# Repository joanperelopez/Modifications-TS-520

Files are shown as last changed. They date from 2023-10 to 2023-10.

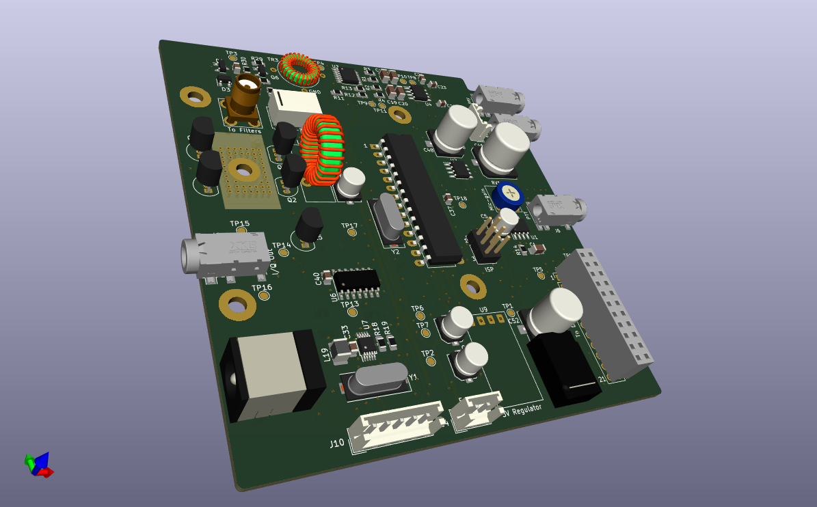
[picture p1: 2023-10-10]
KICAD/mod_TS520/mod_TS520.png

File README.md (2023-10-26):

# Modifications-TS-520

I Started reparing and adjusting my Kenwood transceiver TS-520, but I saw some articles about how to create a device to read the frequency of operation. I decide to include it. I continued including new features as: s-meter, band indicator, spectrum frequency, mode of operation and some others indicators.
As appeared in the picture I use two microcontrollers: one for display and interface, and the second one for the FHT.

This device is inspired in the work of Stephen Leander KV6O, but I changed everything.

On the final PCBs you can see that there are terminals coded from JP1 to JP8. Once the PCB components are assembled, these terminals must be shorted each two with a drop of solder. The grounds of the different circuits are isolated from each other and are only connected to the general ground at these points (star ground).
The VCCs are configured in the same way.

You can use all the documentation that appears in the repository as long as it is not used for commercial purposes.

WhatsApp Image 2023-10-10 at 12 25 15-3

The experiments for the design of the electronic circuits and the microcontroller began with a breadboard and the RF circuits mounted directly on a copper plate.

Top_Assbly

This is the final appearance of the circuit in the TOP side.

Bottom_Assbly

This is the final appearance of the circuit in the BOTTOM side.

The way to calculate the frequency at which the TS-520 emits and receives is a mathematical operation between three different frequencies: CAR which is the frequency of the beat oscillator. VFO which, as its name indicates, is the variable frequency oscillator signal and HET which is a fixed signal from a quartz oscillator and which is different in each band.
Each of these frequencies are amplified and applied to an ATmega328P that makes the readings, the mathematical operations and finally displays the frequency on a graphic screen. 

The band is automatically displayed using the HET information.

The operating mode (USB, LSB and CW) is identified by the frequency of the CAR input and is displayed on the corresponding indicator.

The information from the red LEDs that the TS-520 has is input into the ATmega328P and shown on the display.

The AGC (Automatic Gain Control) signal is conditioned and input into the ATmega328P to display the signal intensity (s-meter).

The RF signal before the SSB and CW filters enters a RF receiver of 3,395MHz that incorporates a Tayloe detector. Once detected, the baseband signal in I/Q format enters the second ATmega328P where it is processed and the FHT is done. This frequency information is transmitted to the first ATmega328P that will display it on the screen. The FHT is like FFT but it uses only the real part, so the CPU load and the complexity is the half.
It is not possible to do the entire process on a single ATmega328P since the FHT consumes almost all the processor resources.

Captura de Pantalla 2023-10-26 a las 16 57 25
PBC layout

Captura de Pantalla 2023-10-26 a las 16 58 39

PCB layout

Schematic

Two shields are provided for the RF sections of the receiver. These should be fitted only after both sections are tested and working correctly.
Connectors J7 and J12 are used to program ATmega328P microcontrollers.
Connectors J5 and J6 connect to the IL9341 2.4" display.

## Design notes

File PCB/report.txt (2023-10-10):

Trazado a '/Users/perelopezveraguas/Documents/Proyectos de RADIOFRECUENCIA/MODIFICACIONES TS-520 /PCB/GERBER/mod_TS520-F_Cu.gbr'.
Trazado a '/Users/perelopezveraguas/Documents/Proyectos de RADIOFRECUENCIA/MODIFICACIONES TS-520 /PCB/GERBER/mod_TS520-B_Cu.gbr'.
Trazado a '/Users/perelopezveraguas/Documents/Proyectos de RADIOFRECUENCIA/MODIFICACIONES TS-520 /PCB/GERBER/mod_TS520-F_Silkscreen.gbr'.
Trazado a '/Users/perelopezveraguas/Documents/Proyectos de RADIOFRECUENCIA/MODIFICACIONES TS-520 /PCB/GERBER/mod_TS520-B_Silkscreen.gbr'.
Trazado a '/Users/perelopezveraguas/Documents/Proyectos de RADIOFRECUENCIA/MODIFICACIONES TS-520 /PCB/GERBER/mod_TS520-F_Mask.gbr'.
Trazado a '/Users/perelopezveraguas/Documents/Proyectos de RADIOFRECUENCIA/MODIFICACIONES TS-520 /PCB/GERBER/mod_TS520-B_Mask.gbr'.
Trazado a '/Users/perelopezveraguas/Documents/Proyectos de RADIOFRECUENCIA/MODIFICACIONES TS-520 /PCB/GERBER/mod_TS520-Edge_Cuts.gbr'.
Archivo de trabajo Gerber '/Users/perelopezveraguas/Documents/Proyectos de RADIOFRECUENCIA/MODIFICACIONES TS-520 /PCB/GERBER/mod_TS520-job.gbrjob' creado.
Info: Listo.

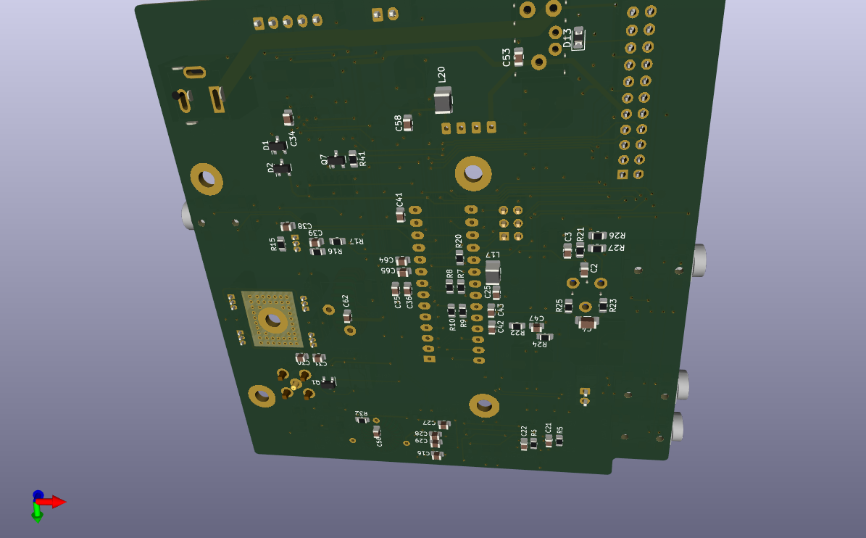
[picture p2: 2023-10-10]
KICAD/mod_TS520/SDR_1.2_Base2.png

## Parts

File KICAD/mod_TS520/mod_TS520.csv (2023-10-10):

Source: | /Users/perelopezveraguas/Documents/KICAD/SDR_1.2/SDR_1.2_Base/SDR_1.2_Base.kicad_sch
Date: | martes, 28 de junio de 2022, 18:18:33
Tool: | Eeschema (6.0.6-0)
Generator: | /Applications/KiCad/KiCad.app/Contents/SharedSupport/plugins/bom_csv_grouped_by_value.py
Component Count: | 147
Individual Components:
Item | Qty | Reference(s) | Value | LibPart | Footprint | Datasheet | Datasheet
 |  | C1 | 1uF | Device:C_Polarized | Capacitor_SMD:C_1206_3216Metric_Pad1.33x1.80mm_HandSolder | ~ | ~
 |  | C2 | 100n | Device:C | Capacitor_SMD:C_0805_2012Metric | ~ | ~
 |  | C3 | 22p | Device:C | Capacitor_SMD:C_0805_2012Metric | ~ | ~
 |  | C4 | 1uF | Device:C_Polarized | Capacitor_SMD:C_1206_3216Metric_Pad1.33x1.80mm_HandSolder | ~ | ~
 |  | C5 | 10uF | Device:C_Polarized | Capacitor_SMD:C_Elec_5x5.4 | ~ | ~
 |  | C6 | 10n | Device:C | Capacitor_SMD:C_0805_2012Metric | ~ | ~
 |  | C16 | 1n | Device:C | Capacitor_SMD:C_0805_2012Metric | ~ | ~
 |  | C17 | .47u | Device:C | Capacitor_SMD:C_1206_3216Metric | ~ | ~
 |  | C18 | .47u | Device:C | Capacitor_SMD:C_1206_3216Metric | ~ | ~
 |  | C19 | .47u | Device:C | Capacitor_SMD:C_1206_3216Metric | ~ | ~
 |  | C20 | .47u | Device:C | Capacitor_SMD:C_1206_3216Metric | ~ | ~
 |  | C21 | 1nF | Device:C | Capacitor_SMD:C_0805_2012Metric | ~ | ~
 |  | C22 | 1nF | Device:C | Capacitor_SMD:C_0805_2012Metric | ~ | ~
 |  | C23 | 100n | Device:C | Capacitor_SMD:C_0805_2012Metric | ~ | ~
 |  | C24 | 100n | Device:C | Capacitor_SMD:C_0805_2012Metric | ~ | ~
 |  | C25 | 100n | Device:C | Capacitor_SMD:C_0805_2012Metric | ~ | ~
 |  | C26 | 100n | Device:C | Capacitor_SMD:C_0805_2012Metric | ~ | ~
 |  | C27 | 100n | Device:C | Capacitor_SMD:C_0805_2012Metric | ~ | ~
 |  | C28 | 10n | Device:C | Capacitor_SMD:C_0805_2012Metric | ~ | ~
 |  | C29 | 100n | Device:C | Capacitor_SMD:C_0805_2012Metric | ~ | ~
 |  | C30 | 100n | Device:C | Capacitor_SMD:C_0805_2012Metric | ~ | ~
 |  | C31 | 33p | Device:C | Capacitor_SMD:C_0805_2012Metric | ~ | ~
 |  | C33 | 100n | Device:C | Capacitor_SMD:C_0805_2012Metric | ~ | ~
 |  | C34 | 1n | Device:C | Capacitor_SMD:C_0805_2012Metric | ~ | ~
 |  | C35 | 100n | Device:C | Capacitor_SMD:C_0805_2012Metric | ~ | ~
 |  | C36 | 10n | Device:C | Capacitor_SMD:C_0805_2012Metric | ~ | ~
 |  | C37 | 100n | Device:C | Capacitor_SMD:C_0805_2012Metric | ~ | ~
 |  | C38 | 10n | Device:C | Capacitor_SMD:C_0805_2012Metric | ~ | ~
 |  | C39 | 10n | Device:C | Capacitor_SMD:C_0805_2012Metric | ~ | ~
 |  | C40 | 100n | Device:C | Capacitor_SMD:C_0805_2012Metric | ~ | ~
 |  | C41 | 10n | Device:C | Capacitor_SMD:C_0805_2012Metric | ~ | ~
 |  | C42 | 100n | Device:C | Capacitor_SMD:C_0805_2012Metric | ~ | ~
 |  | C43 | 10n | Device:C | Capacitor_SMD:C_0805_2012Metric | ~ | ~
 |  | C46 | 250uF | Device:C_Polarized | Capacitor_SMD:C_Elec_10x10.2 | ~ | ~
 |  | C47 | 47n | Device:C | Capacitor_SMD:C_0805_2012Metric | ~ | ~
 |  | C48 | 100uF | Device:C_Polarized | Capacitor_SMD:C_Elec_8x10.2 | ~ | ~
 |  | C52 | 100uF | Device:C_Polarized | Capacitor_SMD:C_Elec_8x10.2 | ~ | ~
 |  | C53 | 100n | Device:C | Capacitor_SMD:C_0805_2012Metric | ~ | ~
 |  | C54 | 100n | Device:C | Capacitor_SMD:C_0805_2012Metric | ~ | ~
 |  | C55 | 100n | Device:C | Capacitor_SMD:C_0805_2012Metric | ~ | ~
 |  | C56 | 100n | Device:C | Capacitor_SMD:C_0805_2012Metric | ~ | ~
 |  | C58 | 100n | Device:C | Capacitor_SMD:C_0805_2012Metric | ~ | ~
 |  | C59 | 10uF | Device:C_Polarized | Capacitor_SMD:C_Elec_5x5.4 | ~ | ~
 |  | C61 | 10uF | Device:C_Polarized | Capacitor_SMD:C_Elec_5x5.4 | ~ | ~
 |  | C62 | 100n | Device:C | Capacitor_SMD:C_0805_2012Metric | ~ | ~
 |  | C63 | 10uF | Device:C_Polarized | Capacitor_SMD:C_Elec_5x5.4 | ~ | ~
 |  | C64 | 12p | Device:C | Capacitor_SMD:C_0805_2012Metric | ~ | ~
 |  | C65 | 12p | Device:C | Capacitor_SMD:C_0805_2012Metric | ~ | ~
 |  | D1 | BAV70 | Diode:BAV70 | Package_TO_SOT_SMD:SOT-23 | https://assets.nexperia.com/documents/data-sheet/BAV70_SER.pdf | https://assets.nexperia.com/documents/data-sheet/BAV70_SER.pdf
 |  | D2 | BAV70 | Diode:BAV70 | Package_TO_SOT_SMD:SOT-23 | https://assets.nexperia.com/documents/data-sheet/BAV70_SER.pdf | https://assets.nexperia.com/documents/data-sheet/BAV70_SER.pdf
 |  | D3 | BAV70 | Diode:BAV70 | Package_TO_SOT_SMD:SOT-23 | https://assets.nexperia.com/documents/data-sheet/BAV70_SER.pdf | https://assets.nexperia.com/documents/data-sheet/BAV70_SER.pdf
 |  | D4 | BAV70 | Diode:BAV70 | Package_TO_SOT_SMD:SOT-23 | https://assets.nexperia.com/documents/data-sheet/BAV70_SER.pdf | https://assets.nexperia.com/documents/data-sheet/BAV70_SER.pdf
 |  | D13 | 20V | Device:D_Zener | Diode_SMD:D_0805_2012Metric_Pad1.15x1.40mm_HandSolder | ~ | ~
 |  | H1 | MountingHole_Pad | Mechanical:MountingHole_Pad | MountingHole:MountingHole_3.2mm_M3_Pad_TopBottom | ~ | ~
 |  | H9 | MountingHole_Pad | Mechanical:MountingHole_Pad | MountingHole:MountingHole_3.2mm_M3_Pad_TopBottom | ~ | ~
 |  | H10 | MountingHole_Pad | Mechanical:MountingHole_Pad | MountingHole:MountingHole_3.2mm_M3_Pad_TopBottom | ~ | ~
 |  | H11 | MountingHole_Pad | Mechanical:MountingHole_Pad | MountingHole:MountingHole_3.2mm_M3_Pad_TopBottom | ~ | ~
 |  | H12 | MountingHole_Pad | Mechanical:MountingHole_Pad | MountingHole:MountingHole_3.2mm_M3_Pad_TopBottom | ~ | ~
 |  | J1 | AudioJack3_PERE | Connector:AudioJack3_PERE | PERE:Jack_3.5mm_PJ311_Horizontal | ~ | ~
 |  | J3 | RF IN/OUT | Connector:Conn_Coaxial | PERE:SMA_Amphenol_901-144_Vertical | ~ | ~
 |  | J4 | AudioJack3_PERE | Connector:AudioJack3_PERE | PERE:Jack_3.5mm_PJ311_Horizontal | ~ | ~
 |  | J5 | AudioJack3_PERE | Connector:AudioJack3_PERE | PERE:Jack_3.5mm_PJ311_Horizontal | ~ | ~
 |  | J6 | AudioJack3_PERE | Connector:AudioJack3_PERE | PERE:Jack_3.5mm_PJ311_Horizontal | ~ | ~
 |  | J7 | ISP | Connector_Generic:Conn_02x03_Counter_Clockwise | PERE:PinHeader_2x03_P2.54mm_Vertical | ~ | ~
 |  | J8 | Barrel_Jack_Switch_Pin3Ring | Connector:Barrel_Jack_Switch_Pin3Ring | PERE:BarrelJack_GCT_DCJ200-10-A_Horizontal | ~ | ~
 |  | J10 | Conn_01x05 | Connector_Generic:Conn_01x05 | Connector_JST:JST_EH_B5B-EH-A_1x05_P2.50mm_Vertical | ~ | ~
 |  | J12 | Conn_02x11_Odd_Even | Connector_Generic:Conn_02x11_Odd_Even | PERE:PinHeader_2x11_P2.54mm_Vertical | ~ | ~
 |  | J14 | Conn_01x02 | Connector_Generic:Conn_01x02 | Connector_JST:JST_EH_B2B-EH-A_1x02_P2.50mm_Vertical | ~ | ~
 |  | J18 | Conn_01x02 | Connector_Generic:Conn_01x02 | Connector_JST:JST_EH_B2B-EH-A_1x02_P2.50mm_Vertical | ~ | ~
 |  | K11 | G6K-2 | Relay:G6K-2 | Relay_SMD:Relay_DPDT_Omron_G6K-2F-Y | http://omronfs.omron.com/en_US/ecb/products/pdf/en-g6k.pdf | http://omronfs.omron.com/en_US/ecb/products/pdf/en-g6k.pdf
 |  | K12 | Tyco | Relay:G6E | PERE:Relay_Single-PERE | https://www.omron.com/ecb/products/pdf/en-g6e.pdf | https://www.omron.com/ecb/products/pdf/en-g6e.pdf
 |  | L16 | 1u | SDR_1-rescue:L_Core_Iron-Device | PERE:Coil_toroid_T50_Vertical
 |  | L17 | 10uH | Device:L_Ferrite | Inductor_SMD:L_1210_3225Metric_Pad1.42x2.65mm_HandSolder | ~ | ~
 |  | L19 | 10uH | Device:L_Ferrite | Inductor_SMD:L_1210_3225Metric_Pad1.42x2.65mm_HandSolder | ~ | ~
 |  | L20 | 10uH | Device:L_Ferrite | Inductor_SMD:L_1210_3225Metric_Pad1.42x2.65mm_HandSolder | ~ | ~
 |  | Q1 | DTC114E | Transistor_BJT:DTC114E | Package_TO_SOT_SMD:SOT-23
 |  | Q2 | BS170 | Transistor_FET:BS170 | Package_TO_SOT_THT:TO-92_Inline | https://www.onsemi.com/pub/Collateral/BS170-D.PDF | https://www.onsemi.com/pub/Collateral/BS170-D.PDF
 |  | Q3 | BS170 | Transistor_FET:BS170 | Package_TO_SOT_THT:TO-92_Inline | https://www.onsemi.com/pub/Collateral/BS170-D.PDF | https://www.onsemi.com/pub/Collateral/BS170-D.PDF
 |  | Q4 | BS170 | Transistor_FET:BS170 | Package_TO_SOT_THT:TO-92_Inline | https://www.onsemi.com/pub/Collateral/BS170-D.PDF | https://www.onsemi.com/pub/Collateral/BS170-D.PDF
 |  | Q5 | BS170 | Transistor_FET:BS170 | Package_TO_SOT_THT:TO-92_Inline | https://www.onsemi.com/pub/Collateral/BS170-D.PDF | https://www.onsemi.com/pub/Collateral/BS170-D.PDF
 |  | Q6 | BFR92A SOT23 | Device:Q_NPN_EBC | Package_TO_SOT_SMD:SOT-23 | ~ | ~
 |  | Q7 | DTC114E | Transistor_BJT:DTC114E | Package_TO_SOT_SMD:SOT-23
 |  | Q8 | BS170 | Transistor_FET:BS170 | Package_TO_SOT_THT:TO-92_Inline | https://www.onsemi.com/pub/Collateral/BS170-D.PDF | https://www.onsemi.com/pub/Collateral/BS170-D.PDF
 |  | R1 | 100 | Device:R | Resistor_SMD:R_0805_2012Metric_Pad1.20x1.40mm_HandSolder | ~ | ~
 |  | R2 | 100 | Device:R | Resistor_SMD:R_0805_2012Metric_Pad1.20x1.40mm_HandSolder | ~ | ~
 |  | R3 | 100 | Device:R | Resistor_SMD:R_0805_2012Metric_Pad1.20x1.40mm_HandSolder | ~ | ~
 |  | R4 | 100 | Device:R | Resistor_SMD:R_0805_2012Metric_Pad1.20x1.40mm_HandSolder | ~ | ~
 |  | R5 | 82k | Device:R | Resistor_SMD:R_0805_2012Metric_Pad1.20x1.40mm_HandSolder | ~ | ~
 |  | R6 | 82k | Device:R | Resistor_SMD:R_0805_2012Metric_Pad1.20x1.40mm_HandSolder | ~ | ~
 |  | R7 | 10k | Device:R | Resistor_SMD:R_0805_2012Metric_Pad1.20x1.40mm_HandSolder | ~ | ~
 |  | R8 | 10k | Device:R | Resistor_SMD:R_0805_2012Metric_Pad1.20x1.40mm_HandSolder | ~ | ~
 |  | R9 | 10k | Device:R | Resistor_SMD:R_0805_2012Metric_Pad1.20x1.40mm_HandSolder | ~ | ~
 |  | R10 | 10k | Device:R | Resistor_SMD:R_0805_2012Metric_Pad1.20x1.40mm_HandSolder | ~ | ~
 |  | R11 | 10k | Device:R | Resistor_SMD:R_0805_2012Metric_Pad1.20x1.40mm_HandSolder | ~ | ~
 |  | R12 | 10k | Device:R | Resistor_SMD:R_0805_2012Metric_Pad1.20x1.40mm_HandSolder | ~ | ~
 |  | R13 | 1k | Device:R | Resistor_SMD:R_0805_2012Metric_Pad1.20x1.40mm_HandSolder | ~ | ~
 |  | R14 | 1K | Device:R | Resistor_SMD:R_0805_2012Metric_Pad1.20x1.40mm_HandSolder | ~ | ~
 |  | R15 | 100k | Device:R | Resistor_SMD:R_0805_2012Metric_Pad1.20x1.40mm_HandSolder | ~ | ~
 |  | R16 | 10k | Device:R | Resistor_SMD:R_0805_2012Metric_Pad1.20x1.40mm_HandSolder | ~ | ~
 |  | R17 | 10k | Device:R | Resistor_SMD:R_0805_2012Metric_Pad1.20x1.40mm_HandSolder | ~ | ~
 |  | R18 | 1k | Device:R | Resistor_SMD:R_0805_2012Metric_Pad1.20x1.40mm_HandSolder | ~ | ~
 |  | R19 | 1k | Device:R | Resistor_SMD:R_0805_2012Metric_Pad1.20x1.40mm_HandSolder | ~ | ~
 |  | R20 | 10k | Device:R | Resistor_SMD:R_0805_2012Metric_Pad1.20x1.40mm_HandSolder | ~ | ~
 |  | R21 | 100k | Device:R | Resistor_SMD:R_0805_2012Metric_Pad1.20x1.40mm_HandSolder | ~ | ~
 |  | R22 | 10 | Device:R | Resistor_SMD:R_0805_2012Metric_Pad1.20x1.40mm_HandSolder | ~ | ~
 |  | R23 | 20k | Device:R | Resistor_SMD:R_0805_2012Metric_Pad1.20x1.40mm_HandSolder | ~ | ~
 |  | R24 | 10 | Device:R | Resistor_SMD:R_0805_2012Metric_Pad1.20x1.40mm_HandSolder | ~ | ~
 |  | R25 | 20k | Device:R | Resistor_SMD:R_0805_2012Metric_Pad1.20x1.40mm_HandSolder | ~ | ~
 |  | R26 | 10k | Device:R | Resistor_SMD:R_0805_2012Metric_Pad1.20x1.40mm_HandSolder | ~ | ~
 |  | R27 | 10k | Device:R | Resistor_SMD:R_0805_2012Metric_Pad1.20x1.40mm_HandSolder | ~ | ~
 |  | R28 | 10k | Device:R | Resistor_SMD:R_0805_2012Metric_Pad1.20x1.40mm_HandSolder | ~ | ~
 |  | R29 | 2k2 | Device:R | Resistor_SMD:R_0805_2012Metric_Pad1.20x1.40mm_HandSolder | ~ | ~
 |  | R30 | 1k | Device:R | Resistor_SMD:R_0805_2012Metric_Pad1.20x1.40mm_HandSolder | ~ | ~
 |  | R31 | 47R | Device:R | Resistor_SMD:R_0805_2012Metric_Pad1.20x1.40mm_HandSolder | ~ | ~
 |  | R32 | 10R | Device:R | Resistor_SMD:R_0805_2012Metric_Pad1.20x1.40mm_HandSolder | ~ | ~
 |  | R33 | 10R | Device:R | Resistor_SMD:R_0805_2012Metric_Pad1.20x1.40mm_HandSolder | ~ | ~
 |  | R41 | 390R | Device:R | Resistor_SMD:R_0805_2012Metric_Pad1.20x1.40mm_HandSolder | ~ | ~
 |  | RV1 | 10k | Device:R_Potentiometer | PERE:Potentiometer_Piher_PT-10-V10_Vertical | ~ | ~
 |  | TP1 | V12 | Connector:TestPoint_Probe | TestPoint:TestPoint_Pad_D1.5mm | ~ | ~
 |  | TP2 | V5 | Connector:TestPoint_Probe | TestPoint:TestPoint_Pad_D1.5mm | ~ | ~
 |  | TP3 | RX1 | Connector:TestPoint_Probe | TestPoint:TestPoint_Pad_D1.5mm | ~ | ~
 |  | TP4 | RX2 | Connector:TestPoint_Probe | TestPoint:TestPoint_Pad_D1.5mm | ~ | ~
 |  | TP5 | Audio 1 | Connector:TestPoint_Probe | TestPoint:TestPoint_Pad_D1.5mm | ~ | ~
 |  | TP6 | CLK0 | Connector:TestPoint_Probe | TestPoint:TestPoint_Pad_D1.5mm | ~ | ~
 |  | TP7 | CLK1 | Connector:TestPoint_Probe | TestPoint:TestPoint_Pad_D1.5mm | ~ | ~
 |  | TP8 | F0 | Connector:TestPoint_Probe | TestPoint:TestPoint_Pad_D1.5mm | ~ | ~
 |  | TP9 | F1 | Connector:TestPoint_Probe | TestPoint:TestPoint_Pad_D1.5mm | ~ | ~
 |  | TP10 | F2 | Connector:TestPoint_Probe | TestPoint:TestPoint_Pad_D1.5mm | ~ | ~
 |  | TP11 | F3 | Connector:TestPoint_Probe | TestPoint:TestPoint_Pad_D1.5mm | ~ | ~
 |  | TP12 | Audio 2 | Connector:TestPoint_Probe | TestPoint:TestPoint_Pad_D1.5mm | ~ | ~
 |  | TP13 | CLK2 | Connector:TestPoint_Probe | TestPoint:TestPoint_Pad_D1.5mm | ~ | ~
 |  | TP14 | TX carrier | Connector:TestPoint_Probe | TestPoint:TestPoint_Pad_D1.5mm | ~ | ~
 |  | TP15 | Signal I | Connector:TestPoint_Probe | TestPoint:TestPoint_Pad_D1.5mm | ~ | ~
 |  | TP16 | Signal Q | Connector:TestPoint_Probe | TestPoint:TestPoint_Pad_D1.5mm | ~ | ~
 |  | TP17 | Modulation | Connector:TestPoint_Probe | TestPoint:TestPoint_Pad_D1.5mm | ~ | ~
 |  | TP18 | V micro | Connector:TestPoint_Probe | TestPoint:TestPoint_Pad_D1.5mm | ~ | ~
 |  | TR3 | 4:1 | :ADT1-1_1 | PERE:Toroid_TR4to1_11mm | https://www.minicircuits.com/pdfs/ADT1-1+.pdf | https://www.minicircuits.com/pdfs/ADT1-1+.pdf
 |  | U1 | TL071 | Amplifier_Operational:TL071 | Package_SO:SOP-8_3.76x4.96mm_P1.27mm | http://www.ti.com/lit/ds/symlink/tl071.pdf | http://www.ti.com/lit/ds/symlink/tl071.pdf
 |  | U2 | LM386 SOP8 | Amplifier_Audio:LM386 | Package_SO:SOP-8_3.76x4.96mm_P1.27mm | http://www.ti.com/lit/ds/symlink/lm386.pdf | http://www.ti.com/lit/ds/symlink/lm386.pdf
 |  | U3 | FST3253 TSSOP16 | FST3253:FST3253 | Package_SO:TSSOP-16_4.4x5mm_P0.65mm
 |  | U4 | LM4562 SOP8 | Amplifier_Operational:LM4562 | Package_SO:SOP-8_3.76x4.96mm_P1.27mm | http://www.ti.com/lit/ds/symlink/lm4562.pdf | http://www.ti.com/lit/ds/symlink/lm4562.pdf
 |  | U6 | 74HC00 SOP14 | 74xx:74HC00 | Package_SO:SO-14_3.9x8.65mm_P1.27mm | http://www.ti.com/lit/gpn/sn74hc00 | http://www.ti.com/lit/gpn/sn74hc00
 |  | U7 | Si5351A MSOP10 | Oscillator:Si5351A-B-GT | Package_SO:MSOP-10_3x3mm_P0.5mm | https://www.silabs.com/documents/public/data-sheets/Si5351-B.pdf | https://www.silabs.com/documents/public/data-sheets/Si5351-B.pdf
 |  | U8 | ATMEGA328P_DIP28 | SDR_LIB_PERE:ATMEGA328P_DIP28 | PERE:DIP-28_W10.16mm_LongPads
 |  | U9 | Regulador_conmutado-PERE | SDR_LIB_PERE:Regulador_conmutado-PERE | PERE:Regulador_conmutado_5V-PERE
 |  | Y1 | 27MHz | Device:Crystal | Crystal:Crystal_SMD_HC49-SD | ~ | ~
 |  | Y2 | 20MHz | Device:Crystal | Crystal:Crystal_SMD_HC49-SD | ~ | ~
Collated Components:
Item | Qty | Reference(s) | Value | LibPart | Footprint | Datasheet | Datasheet
1 | 2 | C1, C4 | 1uF | Device:C_Polarized | Capacitor_SMD:C_1206_3216Metric_Pad1.33x1.80mm_HandSolder | ~ | ~
2 | 19 | C2, C23, C24, C25, C26, C27, C29, C30, C33, C35, C37, C40, C42, C53, C54, C55, C56, C58, C62 | 100n | Device:C | Capacitor_SMD:C_0805_2012Metric | ~ | ~
3 | 1 | C3 | 22p | Device:C | Capacitor_SMD:C_0805_2012Metric | ~ | ~
4 | 4 | C5, C59, C61, C63 | 10uF | Device:C_Polarized | Capacitor_SMD:C_Elec_5x5.4 | ~ | ~
5 | 7 | C6, C28, C36, C38, C39, C41, C43 | 10n | Device:C | Capacitor_SMD:C_0805_2012Metric | ~ | ~
6 | 2 | C16, C34 | 1n | Device:C | Capacitor_SMD:C_0805_2012Metric | ~ | ~
7 | 4 | C17, C18, C19, C20 | .47u | Device:C | Capacitor_SMD:C_1206_3216Metric | ~ | ~
8 | 2 | C21, C22 | 1nF | Device:C | Capacitor_SMD:C_0805_2012Metric | ~ | ~
9 | 1 | C31 | 33p | Device:C | Capacitor_SMD:C_0805_2012Metric | ~ | ~
10 | 1 | C46 | 250uF | Device:C_Polarized | Capacitor_SMD:C_Elec_10x10.2 | ~ | ~
11 | 1 | C47 | 47n | Device:C | Capacitor_SMD:C_0805_2012Metric | ~ | ~
12 | 2 | C48, C52 | 100uF | Device:C_Polarized | Capacitor_SMD:C_Elec_8x10.2 | ~ | ~
13 | 2 | C64, C65 | 12p | Device:C | Capacitor_SMD:C_0805_2012Metric | ~ | ~
14 | 4 | D1, D2, D3, D4 | BAV70 | Diode:BAV70 | Package_TO_SOT_SMD:SOT-23 | https://assets.nexperia.com/documents/data-sheet/BAV70_SER.pdf | https://assets.nexperia.com/documents/data-sheet/BAV70_SER.pdf
15 | 1 | D13 | 20V | Device:D_Zener | Diode_SMD:D_0805_2012Metric_Pad1.15x1.40mm_HandSolder | ~ | ~
16 | 5 | H1, H9, H10, H11, H12 | MountingHole_Pad | Mechanical:MountingHole_Pad | MountingHole:MountingHole_3.2mm_M3_Pad_TopBottom | ~ | ~
17 | 4 | J1, J4, J5, J6 | AudioJack3_PERE | Connector:AudioJack3_PERE | PERE:Jack_3.5mm_PJ311_Horizontal | ~ | ~
18 | 1 | J3 | RF IN/OUT | Connector:Conn_Coaxial | PERE:SMA_Amphenol_901-144_Vertical | ~ | ~
19 | 1 | J7 | ISP | Connector_Generic:Conn_02x03_Counter_Clockwise | PERE:PinHeader_2x03_P2.54mm_Vertical | ~ | ~
20 | 1 | J8 | Barrel_Jack_Switch_Pin3Ring | Connector:Barrel_Jack_Switch_Pin3Ring | PERE:BarrelJack_GCT_DCJ200-10-A_Horizontal | ~ | ~
21 | 1 | J10 | Conn_01x05 | Connector_Generic:Conn_01x05 | Connector_JST:JST_EH_B5B-EH-A_1x05_P2.50mm_Vertical | ~ | ~
22 | 1 | J12 | Conn_02x11_Odd_Even | Connector_Generic:Conn_02x11_Odd_Even | PERE:PinHeader_2x11_P2.54mm_Vertical | ~ | ~
23 | 2 | J14, J18 | Conn_01x02 | Connector_Generic:Conn_01x02 | Connector_JST:JST_EH_B2B-EH-A_1x02_P2.50mm_Vertical | ~ | ~
24 | 1 | K11 | G6K-2 | Relay:G6K-2 | Relay_SMD:Relay_DPDT_Omron_G6K-2F-Y | http://omronfs.omron.com/en_US/ecb/products/pdf/en-g6k.pdf | http://omronfs.omron.com/en_US/ecb/products/pdf/en-g6k.pdf
25 | 1 | K12 | Tyco | Relay:G6E | PERE:Relay_Single-PERE | https://www.omron.com/ecb/products/pdf/en-g6e.pdf | https://www.omron.com/ecb/products/pdf/en-g6e.pdf
26 | 1 | L16 | 1u | SDR_1-rescue:L_Core_Iron-Device | PERE:Coil_toroid_T50_Vertical
27 | 3 | L17, L19, L20 | 10uH | Device:L_Ferrite | Inductor_SMD:L_1210_3225Metric_Pad1.42x2.65mm_HandSolder | ~ | ~
28 | 2 | Q1, Q7 | DTC114E | Transistor_BJT:DTC114E | Package_TO_SOT_SMD:SOT-23
29 | 5 | Q2, Q3, Q4, Q5, Q8 | BS170 | Transistor_FET:BS170 | Package_TO_SOT_THT:TO-92_Inline | https://www.onsemi.com/pub/Collateral/BS170-D.PDF | https://www.onsemi.com/pub/Collateral/BS170-D.PDF
30 | 1 | Q6 | BFR92A SOT23 | Device:Q_NPN_EBC | Package_TO_SOT_SMD:SOT-23 | ~ | ~
31 | 4 | R1, R2, R3, R4 | 100 | Device:R | Resistor_SMD:R_0805_2012Metric_Pad1.20x1.40mm_HandSolder | ~ | ~
32 | 2 | R5, R6 | 82k | Device:R | Resistor_SMD:R_0805_2012Metric_Pad1.20x1.40mm_HandSolder | ~ | ~
33 | 12 | R7, R8, R9, R10, R11, R12, R16, R17, R20, R26, R27, R28 | 10k | Device:R | Resistor_SMD:R_0805_2012Metric_Pad1.20x1.40mm_HandSolder | ~ | ~
34 | 4 | R13, R18, R19, R30 | 1k | Device:R | Resistor_SMD:R_0805_2012Metric_Pad1.20x1.40mm_HandSolder | ~ | ~
35 | 1 | R14 | 1K | Device:R | Resistor_SMD:R_0805_2012Metric_Pad1.20x1.40mm_HandSolder | ~ | ~
36 | 2 | R15, R21 | 100k | Device:R | Resistor_SMD:R_0805_2012Metric_Pad1.20x1.40mm_HandSolder | ~ | ~
37 | 2 | R22, R24 | 10 | Device:R | Resistor_SMD:R_0805_2012Metric_Pad1.20x1.40mm_HandSolder | ~ | ~
38 | 2 | R23, R25 | 20k | Device:R | Resistor_SMD:R_0805_2012Metric_Pad1.20x1.40mm_HandSolder | ~ | ~
39 | 1 | R29 | 2k2 | Device:R | Resistor_SMD:R_0805_2012Metric_Pad1.20x1.40mm_HandSolder | ~ | ~
40 | 1 | R31 | 47R | Device:R | Resistor_SMD:R_0805_2012Metric_Pad1.20x1.40mm_HandSolder | ~ | ~
41 | 2 | R32, R33 | 10R | Device:R | Resistor_SMD:R_0805_2012Metric_Pad1.20x1.40mm_HandSolder | ~ | ~
42 | 1 | R41 | 390R | Device:R | Resistor_SMD:R_0805_2012Metric_Pad1.20x1.40mm_HandSolder | ~ | ~
43 | 1 | RV1 | 10k | Device:R_Potentiometer | PERE:Potentiometer_Piher_PT-10-V10_Vertical | ~ | ~
44 | 1 | TP1 | V12 | Connector:TestPoint_Probe | TestPoint:TestPoint_Pad_D1.5mm | ~ | ~
45 | 1 | TP2 | V5 | Connector:TestPoint_Probe | TestPoint:TestPoint_Pad_D1.5mm | ~ | ~
46 | 1 | TP3 | RX1 | Connector:TestPoint_Probe | TestPoint:TestPoint_Pad_D1.5mm | ~ | ~
47 | 1 | TP4 | RX2 | Connector:TestPoint_Probe | TestPoint:TestPoint_Pad_D1.5mm | ~ | ~
48 | 1 | TP5 | Audio 1 | Connector:TestPoint_Probe | TestPoint:TestPoint_Pad_D1.5mm | ~ | ~
49 | 1 | TP6 | CLK0 | Connector:TestPoint_Probe | TestPoint:TestPoint_Pad_D1.5mm | ~ | ~
50 | 1 | TP7 | CLK1 | Connector:TestPoint_Probe | TestPoint:TestPoint_Pad_D1.5mm | ~ | ~
51 | 1 | TP8 | F0 | Connector:TestPoint_Probe | TestPoint:TestPoint_Pad_D1.5mm | ~ | ~
52 | 1 | TP9 | F1 | Connector:TestPoint_Probe | TestPoint:TestPoint_Pad_D1.5mm | ~ | ~
53 | 1 | TP10 | F2 | Connector:TestPoint_Probe | TestPoint:TestPoint_Pad_D1.5mm | ~ | ~
54 | 1 | TP11 | F3 | Connector:TestPoint_Probe | TestPoint:TestPoint_Pad_D1.5mm | ~ | ~
55 | 1 | TP12 | Audio 2 | Connector:TestPoint_Probe | TestPoint:TestPoint_Pad_D1.5mm | ~ | ~
56 | 1 | TP13 | CLK2 | Connector:TestPoint_Probe | TestPoint:TestPoint_Pad_D1.5mm | ~ | ~
57 | 1 | TP14 | TX carrier | Connector:TestPoint_Probe | TestPoint:TestPoint_Pad_D1.5mm | ~ | ~
58 | 1 | TP15 | Signal I | Connector:TestPoint_Probe | TestPoint:TestPoint_Pad_D1.5mm | ~ | ~
59 | 1 | TP16 | Signal Q | Connector:TestPoint_Probe | TestPoint:TestPoint_Pad_D1.5mm | ~ | ~
60 | 1 | TP17 | Modulation | Connector:TestPoint_Probe | TestPoint:TestPoint_Pad_D1.5mm | ~ | ~
61 | 1 | TP18 | V micro | Connector:TestPoint_Probe | TestPoint:TestPoint_Pad_D1.5mm | ~ | ~
62 | 1 | TR3 | 4:1 | :ADT1-1_1 | PERE:Toroid_TR4to1_11mm | https://www.minicircuits.com/pdfs/ADT1-1+.pdf | https://www.minicircuits.com/pdfs/ADT1-1+.pdf
63 | 1 | U1 | TL071 | Amplifier_Operational:TL071 | Package_SO:SOP-8_3.76x4.96mm_P1.27mm | http://www.ti.com/lit/ds/symlink/tl071.pdf | http://www.ti.com/lit/ds/symlink/tl071.pdf
64 | 1 | U2 | LM386 SOP8 | Amplifier_Audio:LM386 | Package_SO:SOP-8_3.76x4.96mm_P1.27mm | http://www.ti.com/lit/ds/symlink/lm386.pdf | http://www.ti.com/lit/ds/symlink/lm386.pdf
65 | 1 | U3 | FST3253 TSSOP16 | FST3253:FST3253 | Package_SO:TSSOP-16_4.4x5mm_P0.65mm
66 | 1 | U4 | LM4562 SOP8 | Amplifier_Operational:LM4562 | Package_SO:SOP-8_3.76x4.96mm_P1.27mm | http://www.ti.com/lit/ds/symlink/lm4562.pdf | http://www.ti.com/lit/ds/symlink/lm4562.pdf
67 | 1 | U6 | 74HC00 SOP14 | 74xx:74HC00 | Package_SO:SO-14_3.9x8.65mm_P1.27mm | http://www.ti.com/lit/gpn/sn74hc00 | http://www.ti.com/lit/gpn/sn74hc00
68 | 1 | U7 | Si5351A MSOP10 | Oscillator:Si5351A-B-GT | Package_SO:MSOP-10_3x3mm_P0.5mm | https://www.silabs.com/documents/public/data-sheets/Si5351-B.pdf | https://www.silabs.com/documents/public/data-sheets/Si5351-B.pdf
69 | 1 | U8 | ATMEGA328P_DIP28 | SDR_LIB_PERE:ATMEGA328P_DIP28 | PERE:DIP-28_W10.16mm_LongPads
70 | 1 | U9 | Regulador_conmutado-PERE | SDR_LIB_PERE:Regulador_conmutado-PERE | PERE:Regulador_conmutado_5V-PERE
71 | 1 | Y1 | 27MHz | Device:Crystal | Crystal:Crystal_SMD_HC49-SD | ~ | ~
72 | 1 | Y2 | 20MHz | Device:Crystal | Crystal:Crystal_SMD_HC49-SD | ~ | ~

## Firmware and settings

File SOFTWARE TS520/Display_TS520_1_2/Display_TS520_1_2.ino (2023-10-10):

/***************************************************
This program was written by Pere Lopez EA3AGK in order
to create an electronic module to update de Kenwood
TS-520 transceiver. This program control the ILI9341 TFT
and represent the frequency, band, mode, s-meter and the spectrum 
of the IF signal.
****************************************************/

//#include "SPI.h"
#include <Arduino.h>
#include <ILI9341_Fast.h>
#include "Adafruit_GFX.h"
#include <FreqCount.h>
#include <ColorsPere.h>
#include <Play_Regular8pt7b.h>        //(7 x 11 pixels)



#define CODE_VER              "v1.20"
#define BUILD_TYPE            "dev"              // 'dev' = development, 'beta' = bata 'PROD' = production
#define BUILD_DATE            "4-9-2023"          
#define SPLASH_SCREEN_TIME    (3000)             //Splash screen hold time in milliseconds


boolean DEBUG = false;      
boolean DEBUG1 = false;      

//   VARIABLES DEL FFT Y DEL MICRO ESCLAVO
//------------------------------------------

#define   SS_SLAVE      7            //Chip select del micro esclavo. Conectado por SPI. PD7
int   START  = 0xA5;          //Clave que le indica al esclavo mandar el buffer del FFT
//Escribe los valores de la linea de frecuencia
#define offsetX  55
#define offsetY  200                  // Linea de frecuencias
//Escribe las barritas de amplitud del FFT
#define setX    10                    //Se convierte en offset Y al estar girado el display para imprimir en vertical
#define setY    35                    //Se convierte en offset X al estar girado el display para imprimir en vertical

char buffer[128];                      //Este es el buffer que llena el esclavo y que se puede meter directamente en el display
char FFT_Number = 0;
unsigned long last_FFT = 0;


//       VARIABLES DEL S-METER
//------------------------------------------
uint16_t  iTick_color;              //Color de cada componente
int       iTick_pos;                //Posición de los ticks
#define   S_UNITS     A3            //Entrada analógica de lectura del s-meter A3
int test_a = 0;


//       VARIABLES DEL DISPLAY
//-------------------------------———----
#define TFT_CS    10                  //Pines de control
#define TFT_DC    9
#define TFT_RST   8                   //Not used

char cifraNew[9];                     //Donde se almacenan las cifras de la frecuencia
char cifraOld[9];                     //Cifras de la frecuencia anterior
unsigned long lastFrame = millis();

ILI9341 tft = ILI9341(TFT_DC, TFT_RST, TFT_CS);  


//       VARIABLES DEL CONTADOR DE FRECUENCIA
//-------------------------------------------------—
// Averaging variables for smoothing display jitter
const int numReadings = 4;                // number of readings to average over
unsigned long readings[numReadings];      // the readings from the frequency county
//int readIndex = 0;                        // the index of the current reading
//unsigned long total = 0;                  // the running total
//unsigned long average = 0;                // the average
unsigned int  band = 80;                  // Band
// timer varables
//volatile unsigned long timerCounts;
//volatile boolean counterReady;

char mode = 'U';                          // current mode computed from the BFO frequency 
char OldMode = 'S';                       // used in test to see if mode has changed

// counting routine variables
unsigned long overflowCount;
unsigned int timerTicks;
unsigned int timerPeriod;

//Frequency measurement variables
unsigned long frq = 0;                    // From counter
unsigned long vfo = 0;                    // holds measured vfo frequency
unsigned long bfo = 0;                    // holds measured bfo frequency
unsigned long hfo = 0;                    // holds measured hfo frequency (which has been divided by 8 in hardware to get frequency into range that the Arduino can measure)
unsigned long freq = 0;                   // calculated frequency
unsigned long old_freq = 0;               // Para ver si ha cambiado la frecuencia
unsigned long lastbfo = 0;                // holds last bfo frequency to see if it has changed
signed long freqchange = 0;               // holds the hfo/bfo frequency delta from the last measurement
unsigned long fix_hfo = 0;












/////////////////////////////////////////
//    S E T U P
/////////////////////////////////////////
void setup() {
  Serial.begin(115200);
  Serial.setTimeout(300); // Establece un tiempo de espera para recibir datos
  tft.begin();
  tft.setRotation(1);                   //Rota la pantalla
  tft.fillScreen(BLACK);                //Borra la pantalla
  splashScreen();
  writeFreqFixed();                     // Hace el layout de la pantalla: Caracteres fijos de la frecuencia
  freqCounter ();                       // llama al contador de frecuencia
  creaCifrasNew();                      // La frecuencia que será escrita en el display lo metemos en array en formato caracter
  writeFrequency();                     // Escribe la frecuencia
//Inicio del contador de frecuencia
  FreqCount.begin(100);
 //initilize averaging array
for (int thisReading = 0; thisReading < numReadings; thisReading++) { readings[thisReading] = 0;}
  pinMode(S_UNITS, INPUT);              //Analog input for S-Meter
  pinMode(4, OUTPUT);                   //setup pins used to select vfo/bfo/hfo using 74LS153
  pinMode(6, OUTPUT);                   //setup pins used to select vfo/bfo/hfo using 74LS153
//  Micro esclavo
//  SPI.begin();
//  pinMode(MISO, INPUT);
  pinMode(SS_SLAVE, OUTPUT);
  digitalWrite(SS_SLAVE, HIGH);         // Desactiva el esclavo al principio

  last_FFT = millis();
  lastFrame = millis();

  VFO_ON ();
  draw_bar_meter_s();                   //Dibuja el contenedor del s-meter
  init_SpectrumFFT();                   //Dibuja el contenedor del FFT

}




/////////////////////////////////////////////////
//           PROGRAMA PRINCIPAL
/////////////////////////////////////////////////
void loop(void) {

  if ((millis()-lastFrame)>70) {                  //Espera 50 milisegundos
  lastFrame = millis();  
  freqCounter ();                                 //Llama al contador de frecuencia 
  poneModo();                                     //Pone el MODO
  poneBanda();                                    //Pone la banda
  update_s_meter();                               //Actualiza el smeter
  if (old_freq != freq){   
      creaCifrasNew();                                //Crea el array de cifras
      writeFrequency();                           //Nueva frecuencia
        if (freq < 130000) borraPrimerDigito();     // Es 3,5 o 7 MHz. Borra primer dígito 
      } 
  }

if ((millis()-last_FFT)>50) {                  //Espera 20 milisegundos
  last_FFT = millis();
  digitalWrite(SS_SLAVE, LOW);                   //Llama al esclavo
  poneFFTen_Pantalla();
  digitalWrite(SS_SLAVE, HIGH);   
  delay(2); 
  }           
}


///////////////////////////////////////////////////////
//.     RUTINAS FFT
///////////////////////////////////////////////////////


//.   PONE LAS GRAFICAS DE LA FFT EN PANTALLA
void poneFFTen_Pantalla() { 

while (Serial.available() > 0) {
    char c = Serial.read();                       // Leer y descartar cada byte del buffer
    }

int separacion = 2;     
      while (Serial.available() == 0);            //Mira si le ha llegado el buffer desde el esclavo
      Serial.readBytes(buffer, sizeof(buffer));
      
      for(int i = 2; i<=127; i++){                //126 bins

      tft.drawLine(offsetX+separacion*i, offsetY, offsetX+separacion*i, offsetY-75, BLACK); //Se borra el anterior valor
      tft.drawLine(offsetX+separacion*i, offsetY, offsetX+separacion*i, offsetY-buffer[i], WHITE);  //Se muestra el nuevo valor
      }

  }
  




//.  PONE EL CONTENEDOR Y EL EJE DE FRECUENCIAS DE LA FFT
//-------------------------------------------------------------
void init_SpectrumFFT(){            //Pone el contenedor del FFT
    tft.setRotation(0);             //Para que imprima las frecuencias en vertical
    tft.setTextSize(1);             // Definimos tamaño del texto. (Probado tamaños del 1 al 10) 
    tft.setTextColor(WHITE);        // Definimos el color del texto  

    float o_freq = -10.5;           //Para imprimr las frecuencias relativas del FFT

    for (int i=1; i<=15; i++) {
      if ((i>=2&&i<=7)||(i==15)) tft.setCursor( setX-6 , (18*i) + setY );   //Esta y las sigueintes dos lineas compensan la altura de los carteles
      else if  (i==1)            tft.setCursor( setX-12 , (18*i) + setY );  
      else                       tft.setCursor( setX , (18*i) + setY );         
      tft.println((o_freq));        //Imprime las frecuencias
      o_freq +=1.5;
    }
  tft.setRotation(1);               //Vuelve a la rotacion normal

  }





///////////////////////////////////////////////////////
//    BLOQUE DE RUTINAS DEL S-METER
///////////////////////////////////////////////////////

//Define colors for bar meter elements using RGB565 format
//see: http://www.barth-dev.de/online/rgb565-color-picker/
const uint16_t BARMETER_GRAY = 0x8430;    //Gray color in RGB565 format.
const uint16_t BARMETER_MGRAY = RGBto565(50,50,50);    //Medium Gray color in RGB565 format.
const uint16_t BARMETER_BLUE = 0x02D9;    //Blue color
const uint16_t BARMETER_RED  = 0xD8E5;    //Tercera parte de la barra
const uint16_t BARMETER_YELLOW = 0xFF80;  //Segunda parte de la barra
const uint16_t BARMETER_DARK  = 0x2124;   //bar pointer when off
const uint16_t BARMETER_GREEN  = 0x07E0;  //Primera parte de la barra

// Dibujo del contenedor y las marcas del s-meter
#define INI_SX      70              //Posición X donde empieza el s-meter
#define INI_SM      INI_SX-3        // Inicio de las marcas
#define INI_SY      100             // Posición Y
#define S_WG         177            // anchura Linea gris superior
#define S_WR         83             // anchura Linea roja superior
#define S_WGI        235            // anchura Linea gris inferior
#define S_END       INI_SX+230      // Cierre final del contenedor
#define S_H         16              // Altura dwel contenedor
#define S_GRUESO     2             // Grososr del contenedor
#define S_DIST       17             // Distancia entre marcas
// Dibujo de las barritas dentro del s-meter
#define INI_XBAR    INI_SX      // Donde se emplieza a dibujar las barras X 20
#define INI_YBAR    INI_SY+4        // 72
      // Donde se emplieza a dibujar las barras Y
#define S_ALT       S_H-6           // Altura de las barra
#define S_COL1      34              //Dónde se empiezan a poner barritas amarillas
#define S_COL2      62              //Dónde se empiezan a poner barritas rojas

#define   FROM_LOW    350             //Límite bajo de lectura del ADC
#define   FROM_HIGH   640           //Limite de lectura alto del ADC
#define   TO_LOW      95            //Mínimo del mapeado. Antes 3
#define   TO_HIGH     2           //Máximo del mapeado. Antes 100

// Crea la parte fija del s-meter
//--------------------------------
void draw_bar_meter_s(void){

// Dibuja las líneas del s-meter
  tft.drawRect(INI_SX, INI_SY, S_WG,S_GRUESO, BARMETER_GRAY);    //Linea superior izquierda
  tft.drawRect(150+INI_SX, INI_SY, S_WR,S_GRUESO, BARMETER_RED);  //Linea superior derecha roja
  tft.fillRect(INI_SX, INI_SY, S_GRUESO+1,S_H, BARMETER_GRAY);        //Línea vertical izquierda
  tft.fillRect(S_END, INI_SY, S_GRUESO+1,S_H, BARMETER_RED);        //Línea vertical derecha
  tft.drawRect(INI_SX, INI_SY+S_H, S_WG,S_GRUESO, BARMETER_GRAY);    //Linea inferior izquierda
  tft.drawRect(150+INI_SX, INI_SY+S_H, S_WR,S_GRUESO, BARMETER_RED);  //Linea inferior derecha roja 

  //Set text font and size
  tft.setFont(&Play_Regular8pt7b); //font
  tft.setTextSize(1);

  //Add "S" indicator 
  tft.setCursor(INI_SX-15 ,INI_SY+12); //(x,y)
  tft.setTextColor(BARMETER_GRAY);
  tft.println(F("S"));
 
  for (int i=1; i<14; i++) {
    if (i>9) iTick_color=BARMETER_RED; else iTick_color=BARMETER_GRAY;
    tft.fillRect(INI_SM+(S_DIST*i), INI_SY-5, 3,7, iTick_color);        // Pone las marcas
    if (i%2)  {

      if (i<=9) {
        tft.setCursor(INI_SM+(S_DIST*i)-4,INI_SY-10);                       //Dibuja números del 1 al 9      
        tft.print(i);
        } // Final números

      if (i==11) {
        tft.setTextColor(BARMETER_RED);
        tft.setCursor(INI_SM+(S_DIST*i)-14,INI_SY-10);                       //Dibuja +20dB     
        tft.print("+20");
        }

        if (i==13) {
        tft.setTextColor(BARMETER_RED);
        tft.setCursor(INI_SM+(S_DIST*i)-14,INI_SY-10);                       //Dibuja +40db      
        tft.print("+40");
        }
    } // (i%2)
  }  // for...
tft.setFont(); // Standard font
}


//-------------------------------------------------------------------------------
void update_s_meter() {
  int iAnalog_value=0;                      //Temp variable to hold analog value from analogRead() so analog-in pin only needs to be scanned once
  int val;

  for (int i=0; i<10; i++) {
    val = analogRead(S_UNITS);
    iAnalog_value += val;
    }
  iAnalog_value /= 10;

 //Read analog input and convert to TO_LOW to TO_HIGH
  iAnalog_value = map(iAnalog_value, FROM_LOW, FROM_HIGH, TO_LOW, TO_HIGH);    //Mapea la lectura del ADC para darle el rango correcto 
  if (iAnalog_value<2) iAnalog_value = 2;
  deflect_bar_meter(INI_XBAR,INI_YBAR,iAnalog_value,S_COL1,S_COL2);           //Llama a actualizar las barritas del s-meter

/*
// For testing pourposes
  test_a = (analogRead(S_UNITS));
  Serial.print ("ADC mapeado: ");
  Serial.print (iAnalog_value);
  Serial.print ("   ADC:  ");
  Serial.print (test_a);
  Serial.print (" iAnalog_value:   "); 
  Serial.println (iAnalog_value);
*/
} //<end> function update_s_meter()



//         CREA LAS BARRITAS DEL S-METER CON SUS DISTINTOS COLORES
//-------------------------------------------------------------------------------
// iXpos, and iYpos is meter position.
// iValue is level 0-100 of deflection.
// iCaution is level at which bar turns yellow.
// iWarning is level at which bar turns red.
// if level is greater than 100, entire bar turns red
void deflect_bar_meter(int iXpos, int iYpos, int iValue, int iCaution, int iWarning) {

  uint16_t iBarSeg_color = BARMETER_DARK;

  //Calcula las barritas que hay que pintar en función de lo que ha leido desde el ADC
  int iBarSeg_y = INI_YBAR;                       //Absolute Y screen position for all bar segments
  int iBarSeg_value = INI_XBAR+(iValue/2*5);      //Absolute X screen position for value segment
  int iBarSeg_warning = INI_XBAR+(iWarning/2*5);  //Absolute X screen position for warning segment
  int iBarSeg_caution = INI_XBAR+(iCaution/2*5);  //Absolute X screen position for caution segment
  int iBarSeg_zero = INI_XBAR;                    //Absolute position of bar segment zero value
  int iBarSeg_pos = INI_XBAR+220;                 //Absolute current bar-meter segment position, set to full scale initially +220

// Pinta las barritas de los diferentes segmentos del s-meter
  for( ; iBarSeg_pos>iBarSeg_zero; iBarSeg_pos-=5) {               //Start at the full scale position and work back to zero

    if(iBarSeg_pos <= iBarSeg_value){

      if(iBarSeg_pos >= iBarSeg_warning){iBarSeg_color = BARMETER_RED;}           //Tercera parte del s-meter
      else if(iBarSeg_pos >= iBarSeg_caution){iBarSeg_color = BARMETER_YELLOW;}   //Segunda parte del s-meter
      else iBarSeg_color = BARMETER_GREEN;                                        //Primera parte del s-meter

    }
    else iBarSeg_color = BARMETER_MGRAY;                                          //Fondo del s-meter
    tft.fillRect(iBarSeg_pos, iBarSeg_y, 3,S_ALT, iBarSeg_color);

  }

}








///////////////////////////////////////////////////////
//    BLOQUE DE RUTINAS DEL DISPLAY TFT ILI9341
///////////////////////////////////////////////////////
//
//  FUNCIONES:
//  ILI9341.fillScreen(ILI9341_GREEN);              //Rellena toda la pantalla
//  ILI9341.setTextColor(ILI9341_YELLOW);           //Cambiar color de texto
//  ILI9341.setTextSize(2);                         //Cambiar tamaño del texto
//  ILI9341.println("my foonting turlingdromes.");  //Poner un texto en pantalla
//  ILI9341.setCursor(0, 0);                        //Situar el cursor
//  ILI9341.fillRect(X, Y, W, H, ILI9341_BLACK);    //Rellenar en negro una parte del display
//  ILI9341.setRotation(1);                         //Rota la pantalla
//  ILI9341.fillRect(int16_t x, int16_t y, int16_t w, int16_t h, uint16_t color);
//  ILI9341.drawFastHLine(int16_t x, int16_t y, int16_t w, uint16_t color);
//  ILI9341.drawFastVLine(int16_t x, int16_t y, int16_t h, uint16_t color);
//  drawCircle(int16_t x0, int16_t y0, int16_t r, uint16_t color);
//  drawCircleHelper(int16_t x0, int16_t y0, int16_t r, uint8_t cornername, uint16_t color);
//  fillCircle(int16_t x0, int16_t y0, int16_t r, uint16_t color);
//  fillCircleHelper(int16_t x0, int16_t y0, int16_t r, uint8_t cornername, int16_t delta, uint16_t color);
//  void drawTriangle(int16_t x0, int16_t y0, int16_t x1, int16_t y1, int16_t x2, int16_t y2, uint16_t color);
//  void fillTriangle(int16_t x0, int16_t y0, int16_t x1, int16_t y1, int16_t x2, int16_t y2, uint16_t color);
//  void drawRoundRect(int16_t x0, int16_t y0, int16_t w, int16_t h, int16_t radius, uint16_t color);
//   void fillRoundRect(int16_t x0, int16_t y0, int16_t w, int16_t h, int16_t radius, uint16_t color);
//  void drawBitmap(int16_t x, int16_t y, const uint8_t bitmap[], int16_t w, int16_t h, uint16_t color);
//  void drawBitmap(int16_t x, int16_t y, const uint8_t bitmap[], int16_t w, int16_t h, uint16_t color, uint16_t bg);
//  void drawBitmap(int16_t x, int16_t y, uint8_t *bitmap, int16_t w, int16_t h, uint16_t color);
//   void drawBitmap(int16_t x, int16_t y, uint8_t *bitmap, int16_t w, int16_t h, uint16_t color, uint16_t bg);
//  void drawXBitmap(int16_t x, int16_t y, const uint8_t bitmap[], int16_t w, int16_t h, uint16_t color);
//  void drawGrayscaleBitmap(int16_t x, int16_t y, const uint8_t bitmap[], int16_t w, int16_t h);
//  void drawGrayscaleBitmap(int16_t x, int16_t y, uint8_t *bitmap, int16_t w, int16_t h);
//  void drawGrayscaleBitmap(int16_t x, int16_t y, const uint8_t bitmap[], const uint8_t mask[], int16_t w, int16_t h);
//  void drawGrayscaleBitmap(int16_t x, int16_t y, uint8_t *bitmap, uint8_t *mask, int16_t w, int16_t h);
//  void drawRGBBitmap(int16_t x, int16_t y, const uint16_t bitmap[], int16_t w, int16_t h);
//  void drawRGBBitmap(int16_t x, int16_t y, uint16_t *bitmap, int16_t w, int16_t h);
//  void drawRGBBitmap(int16_t x, int16_t y, const uint16_t bitmap[], const uint8_t mask[], int16_t w, int16_t h);
//  void drawRGBBitmap(int16_t x, int16_t y, uint16_t *bitmap, uint8_t *mask, int16_t w, int16_t h);
//  void drawChar(int16_t x, int16_t y, unsigned char c, uint16_t color, uint16_t bg, uint8_t size);
//  void drawChar(int16_t x, int16_t y, unsigned char c, uint16_t color, uint16_t bg, uint8_t size_x, uint8_t size_y);
//  void getTextBounds(const char *string, int16_t x, int16_t y, int16_t *x1, int16_t *y1, uint16_t *w, uint16_t *h);
//  void getTextBounds(const __FlashStringHelper *s, int16_t x, int16_t y, int16_t *x1, int16_t *y1, uint16_t *w, uint16_t *h);
//  void getTextBounds(const String &str, int16_t x, int16_t y, int16_t *x1, int16_t *y1, uint16_t *w, uint16_t *h);
//  void setTextSize(uint8_t s);
//  void setTextSize(uint8_t sx, uint8_t sy);
//  void setFont(const GFXfont *f = NULL);
//  virtual void invertDisplay(bool i);
//  virtual void endWrite(void);
//  virtual void drawPixel(int16_t x, int16_t y, uint16_t color) = 0;
//   virtual void startWrite(void);
//   virtual void endWrite(void);

/*
// Color definitions
#define P_BLACK 0x0000                          ///<   0,   0,   0
#define P_NAVY 0x000F                           ///<   0,   0, 123
#define P_DARKGREEN 0x03E0                      ///<   0, 125,   0
#define P_DARKCYAN 0x03EF                       ///<   0, 125, 123
#define P_MAROON 0x7800                         ///< 123,   0,   0
#define P_PURPLE 0x780F                         ///< 123,   0, 123
#define P_OLIVE 0x7BE0                          ///< 123, 125,   0
#define P_LIGHTGREY 0xC618                      ///< 198, 195, 198
#define P_DARKGREY 0x7BEF                       ///< 123, 125, 123
#define p_BLUE 0x001F                           ///<   0,   0, 255
#define p_GREEN 0x07E0                          ///<   0, 255,   0
#define p_CYAN 0x07FF                           ///<   0, 255, 255
#define p_RED 0xF800                            ///< 255,   0,   0
#define p_MAGENTA 0xF81F                        ///< 255,   0, 255
#define p_YELLOW 0xFFE0                         ///< 255, 255,   0
#define P_WHITE 0xFFFF                          ///< 255, 255, 255
#define P_ORANGE 0xFD20                         ///< 255, 165,   0
#define P_GREENYELLOW 0xAFE5                    ///< 173, 255,  41
#define P_PINK 0xFC18                           ///< 255, 130, 198
#define P_GREY  RGBto565(128,128,128)
#define P_LGREY RGBto565(160,160,160)
#define P_DGREY RGBto565( 80, 80, 80)
#define P_LBLUE RGBto565(100,100,255)
#define P_DBLUE RGBto565(  0,  0,128)
*/

//
//
//  unsigned long start = micros();                 //Cálculo de tioempo
//  return micros() - start;                        //Cálculo de tiempo

// Display de la frecuencia
#define INI_FX      50    //Posición X donde empieza la frecuencia
#define INI_FY      25    //Posición Y
#define W_F         235   //Anchura
#define H_F         30    //Altura
#define anchoChar_F 25    //anchura de cada caracter de la frecuencia
#define MHZ_TEXT    180   //Lugar donde se escribe "Mhz"
#define COLOR_F     WHITE
#define COLOR_MHZ   P_YELLOW
#define COLOR_FBG   P_DBLUE
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

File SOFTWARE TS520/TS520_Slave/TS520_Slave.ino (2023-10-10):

#include <Arduino.h>
#include <Wire.h>
//#include <Adafruit_SI5351.h>

#include "si5351.h"

//Adafruit_SI5351 clockgen = Adafruit_SI5351();

Si5351 si5351;

#define LOG_OUT 1 // use the log output function
#define FHT_N 256 // set to 256 point fht
#include <FHT.h> // include the library


#define offsetX  50
#define offsetY  200
#define SS_SLAVE 3        //Chip select PD2
int FFT_Number = 0;
char buffer[128]; 

int32_t cal_factor = 118800;                          //Buscado experimentalmente

void setup() {
unsigned long long freq = 338550000ULL;               //Frecuencia de salida
unsigned long long pll_freq = 60261900000ULL;         //Frecuencia del PLL
//unsigned long long pll_freq = 56017500000ULL;         //Forzado el PLL a bajar de frecuencia para mejorar el ajuste de fase
bool i2c_found;


  // Start serial and initialize the Si5351
  Serial.begin(115200);

  i2c_found = si5351.init(SI5351_CRYSTAL_LOAD_8PF, 0, 0);
  if(!i2c_found)
  {
    Serial.println("Device not found on I2C bus!");
  }

  si5351.set_ms_source(SI5351_CLK0, SI5351_PLLA);           //Origen de cada salida
  si5351.set_ms_source(SI5351_CLK1, SI5351_PLLA);

  si5351.set_freq_manual(freq, pll_freq, SI5351_CLK0);      //Pone las frecuencias de salida y la frecuencia del PLL
  si5351.set_freq_manual(freq, pll_freq, SI5351_CLK1);

  si5351.set_correction(cal_factor, SI5351_PLL_INPUT_XO);   //Factor de correccion de los errores

  si5351.set_phase(SI5351_CLK0, 0);                         // Fases en cuadratura
  si5351.set_phase(SI5351_CLK1, 127);

  si5351.pll_reset(SI5351_PLLA);                            //Resetear para que inicie correctamente las fases

  si5351.update_status();

  TIMSK0 = 0;                     // turn off timer0 for lower jitter
  ADCSRA = 0xe5;                  // set the adc to free running mode
  ADMUX = 0x40;                   // use adc0
  DIDR0 = 0x01;                   // turn off the digital input for adc0

}



void loop() {

while (digitalRead(SS_SLAVE) == HIGH);    // Espera hasta que el maestro active SS
  
  creaFFT();                              //Si. Crea la FFT y la manda al maestro


  
}

//  CREA LA FFT Y MANDA LOS DATOS AL MAESTRO
//--------------------------------------------
void creaFFT() {
//  while(1) {                                // reduces jitter
    cli();                                    // UDRE interrupt slows this way down on arduino1.0
    for (int i = 0 ; i < FHT_N ; i++) {       // save 256 samples
      while(!(ADCSRA & 0x10));                // wait for adc to be ready
      ADCSRA = 0xf5;                          // restart adc
      byte m = ADCL;                          // fetch adc data
      byte j = ADCH;
      int k = (j << 8) | m;                   // form into an int
      k -= 0x0200;                            // form into a signed int
      k <<= 6;                                // form into a 16b signed int
      fht_input[i] = k;                       // put real data into bins
    }
  fht_window();                               // window the data for better frequency response
  fht_reorder();                              // reorder the data before doing the fht
  fht_run();                                  // process the data in the fht
  fht_mag_log();                              // take the output of the fht
  sei();
  //Serial.println("Pasada 1");
  for(int i = 0; i<=127; i++){                //126 bins
      FFT_Number = fht_log_out[i]-15;            //Filtro digital. Creo que regula la amplitud
      if  (FFT_Number <= 0){FFT_Number = 0;}  //Evita números negativos
      buffer[i] = FFT_Number;                 //Llena el buffer para el maestro
    }
  compensar();                                //Iguala los valores del array
  Serial.write(buffer, sizeof(buffer));       // Envía el buffer completo al maestro
  while (digitalRead(SS_SLAVE) == LOW);       // Espera hasta que el maestro desactive SS
  }


void compensar() {
// Compensar el array
  // Compensación proporcional para ajustar valores entre 0 y 60
  for (int i = 0; i <= 127; i++) {
    buffer[i] = map(buffer[i], 0, 127, 0, 110);
    if  (buffer[i] < 0){buffer[i] = 0;}
  }

  // Compensación proporcional para ajustar valores en función de la posición
  for (int i = 0; i <= 127; i++) {
    float factor = 0.07 + 0.5 * (float)i / 100; // Ajusta el factor de 0.4 a 1 linealmente
    buffer[i] = buffer[i] * factor;
  }

}
